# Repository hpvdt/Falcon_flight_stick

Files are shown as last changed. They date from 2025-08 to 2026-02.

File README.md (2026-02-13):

# Falcon Flight Stick
A custom-designed **flight control stick** for the Falcon Aircraft project — designing both **hardware and firmware** for force sensing, CAN communication, and USB HID joystick interfacing.




---

## Overview
The **Falcon Flight Stick** is a force-sensing joystick that measures user input via strain gauges and communicates with the aircraft’s control system through **CAN bus** or to a computer host via **USB-C**.  
This project demonstrates my ability to proficiently design, route, and program an embedded system from the ground up — including power delivery, signal integrity, and firmware architecture.

---

## Key Features
- **MCU Core:** STM32F103CBU6 managing all board-level events with an external 8Mhz Oscillator
- **Sensing System:** Three strain gauges read via a precision Texas Instruments ADS131M03IRUK ADC (32-bit SPI interface)  
- **Connectivity:**  
  - USB-C (HID joystick or virtual COM port)  
  - CAN bus daisy-chain communication  
- **Memory:** 1×128-byte EEPROM for calibration data 
- **Power System:**  
  - TI TPS62177 step-down converter for higher current ditial power
  - ADI LT1962 LDO (3.3V)  for low noise, low current analog power
  - Automatic protection between USB-C and LiPo (12V) sources 
- **PCB Stackup:** 4-layer board with separated analog/digital planes for signal integrity
- **Breakout Button Matrix:**
  - button matrix allowing for a hotswappable and fully customizable button interface on the joystick
  - Up to 25 individual buttons, all allowable for interrupts

---

## Hardware Design

### Hardware Repository
The latest hardware version is **Falcon Flight Stick Rev5**.  
Previous revisions were experimental or undocumented.

### Design Breakdown


The STM32 MCU is programmed through **ST-LinkV3 (SWD)** and communicates via **UART** for debug and development.  
Differential USB data lines enable HID or COM functionality, depending on firmware.  

Strain gauge signals are processed through a TI ADC, which triggers SPI reads via a DRDY interrupt.  
Processed values are sent to the servo controller board (via CAN) or USB interface.  

---

## Power Architecture


The power subsystem ensures stable operation from multiple sources:
- **12V LiPo (CAN chain)** or **5V USB-C**
- Both inputs are protected from backfeed
- Outputs:  
  - 3.3V Digital (MCU, logic)  
  - 3.3V Analog (ADC, strain gauge front-end)

These rails are physically isolated to minimize noise and ground-reference drift.

---

## Schematics
Full schematic set:  
Schematic

---

## PCB Layout

### Summary
- 4-layer stackup for power and noise isolation  
- Separated analog/digital ground and power planes  
- Power trace widths sized by current draw  
- Labelled parts for developer readability  

### Views
**Full Layout:**  


**Layer 1: Signal**  


**Layer 2: Power**  


**Layer 3: GND / AGND**  


**Layer 4: Signal 2**  


---

## 3D Model



---

## Firmware (Planned / In Progress)

Example outline:
- USB HID joystick emulation via STM32 HAL  
- CAN message handling for actuator control  
- ADC data acquisition and digital filtering  
- EEPROM calibration storage  

---

## Tools Used
- **KiCad 8.0** – PCB and schematic design  
- **STM32CubeIDE** – Firmware development  & MCU pinout planning
- **JLCPCB** – Fabrication and assembly  
- **SolidWorks** – 3D mechanical integration  
- **GitHub / Git** – Version control  

---

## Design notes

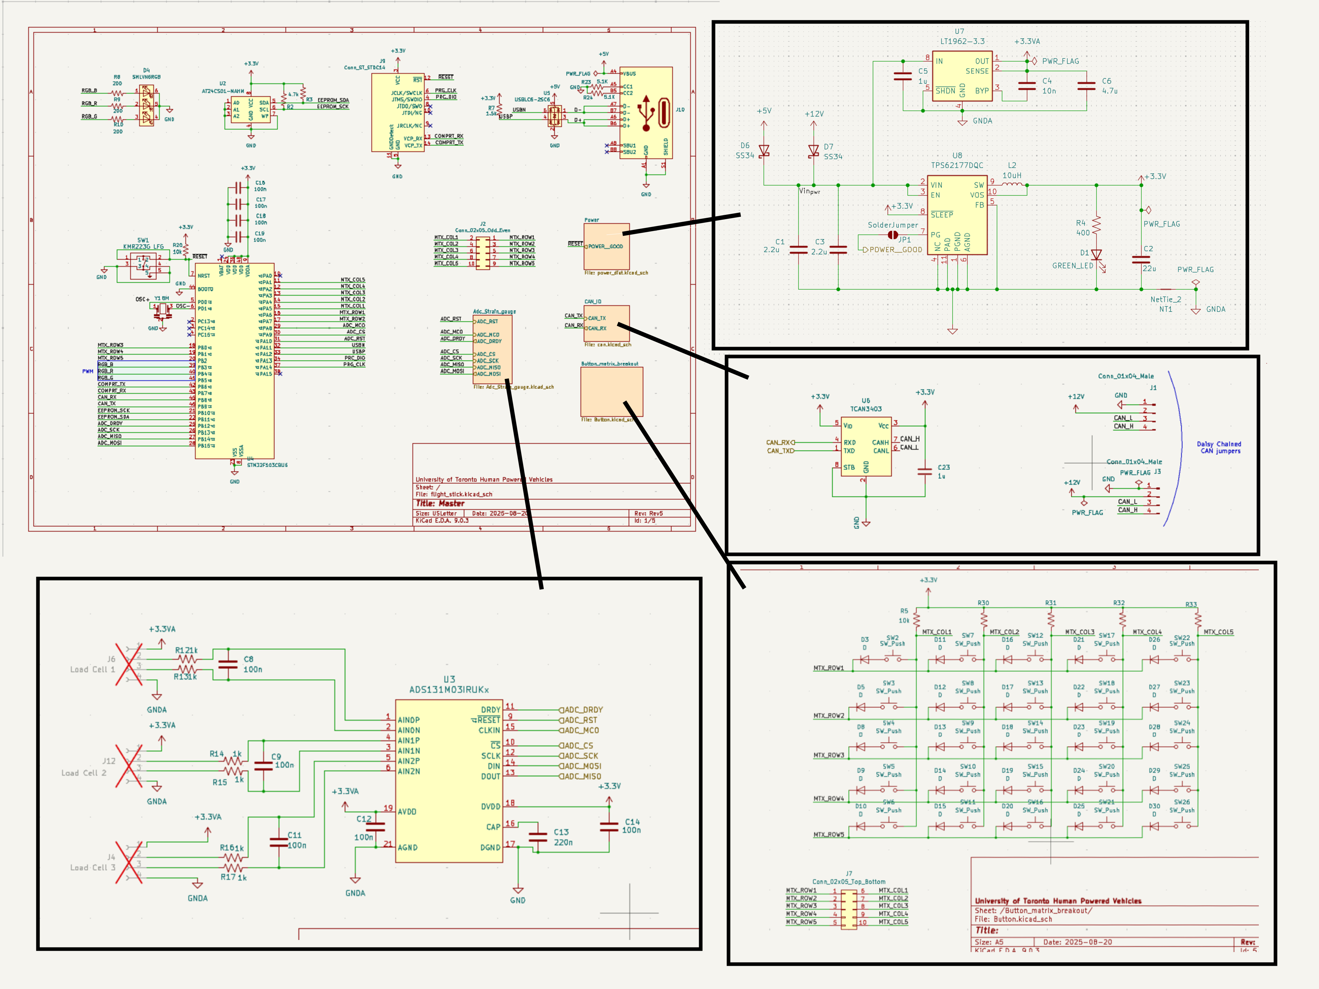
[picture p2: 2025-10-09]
hardware/PCBSchematic.jpg

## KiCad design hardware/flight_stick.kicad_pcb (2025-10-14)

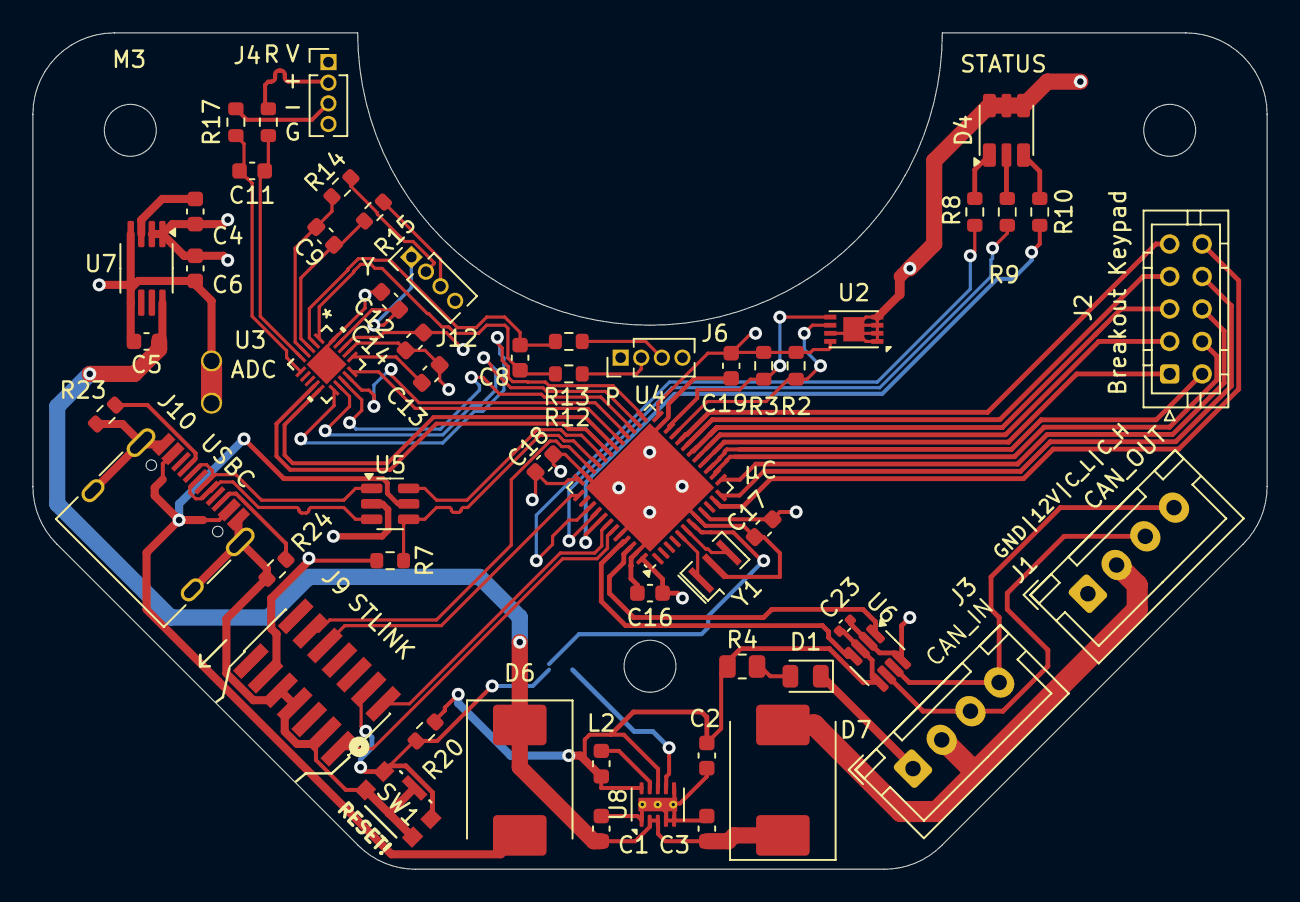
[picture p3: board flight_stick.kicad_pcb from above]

Board: 4 copper layers, 76.0 x 51.5 mm, 60 parts (1 on the bottom side), 66 nets.

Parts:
C1, C3: 2.2u; C_0603_1608Metric
C2: 22u; C_0603_1608Metric
C4: 10n; C_0603_1608Metric
C5: 1u; C_0603_1608Metric
C6: 4.7u; C_0603_1608Metric
C8, C9, C11, C12, C14, C16, C17, C18, C19: 100n; C_0603_1608Metric
C13: 220n; C_0603_1608Metric
C23: 1u; C_0402_1005Metric
D1: GREEN_LED; LED_0805_2012Metric
D4: SMLVN6RGB; LED_ROHM_SMLVN6
D6, D7: SS34; D_SMC
H1, H2, H3: MountingHole; MountingHole_3.2mm_M3
J1, J3: Conn_01x04_Male; JST_XH_B4B-XH-A_1x04_P2.50mm_Vertical
J2: Conn_02x05_Odd_Even; JST_PHD_B10B-PHDSS_2x05_P2.00mm_Vertical
J4: Load Cell 3; PinHeader_1x04_P1.27mm_Vertical
J6: Load Cell 1; PinHeader_1x04_P1.27mm_Vertical
J9: Conn_ST_STDC14; PinHeader_2x07_P1.27mm_Vertical_SMD
J10: USB_C_Receptacle_USB2.0; USB_C_Receptacle_HRO_TYPE-C-31-M-12
J12: Load Cell 2; PinHeader_1x04_P1.27mm_Vertical
JP1: SolderJumper; SolderJumper-2_P1.3mm_Open_TrianglePad1.0x1.5mm
L2: 10uH; L_0603_1608Metric
NT1: NetTie_2; NetTie-2_THT_Pad1.0mm
R2, R3: 4.7k; R_0603_1608Metric
R4: 400; R_0805_2012Metric
R7: 1.5k; R_0603_1608Metric
R8, R9, R10: 200; R_0603_1608Metric
R12, R13, R14, R15, R16, R17: 1k; R_0603_1608Metric
R20: 10k; R_0603_1608Metric
R23, R24: 5.1K; R_0603_1608Metric
SW1: KMR223G LFG; KMR2_G_CNK
U2: AT24CS01-MAHM; DFN-8-1EP_3x2mm_P0.5mm_EP1.3x1.5mm
U3: ADS131M03IRUKx; QFN_WQFN_RUK_TEX
U4: STM32F103CBU6; QFN-48-1EP_7x7mm_P0.5mm_EP5.6x5.6mm
U5: USBLC6-2SC6; SOT-23-6
U6: TCAN3403; TSOT-23-8
U7: LT1962-3.3; MSOP-8_3x3mm_P0.65mm
U8: TPS62177DQC; WSON-10-1EP_2x3mm_P0.5mm_EP0.84x2.4mm_ThermalVias
Y1: 8M; Resonator_SMD_Murata_CSTxExxV-3Pin_3.0x1.1mm

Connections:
+3.3V: C2.1, C14.1, C16.2, C17.2, C18.2, C19.1, C23.1, J9.3 (VCC), L2.2, R2.1, R3.1, R4.1, R7.1, R20.1, U2.8 (VCC), U3.18 (DVDD), U4.9 (VDDA), U4.24 (VDD), U4.36 (VDD), U4.48 (VDD), U6.3 (V_{CC}), U6.5 (V_{IO}), U8.8 (~SLEEP), U8.10 (VOS)
+3.3VA: C4.1, C6.1, C12.1, J4.1, J6.1, J12.1, U3.19 (AVDD), U7.1 (OUT), U7.2 (SENSE)
+5V: D6.2 (A), J10.A4 (VBUS), J10.A9 (VBUS), J10.B4 (VBUS), J10.B9 (VBUS), U5.5 (VBUS)
+12V: D7.2 (A), J1.2, J3.2
/ADC_CS: U3.10 (~CS), U4.30 (PA9)
/ADC_DRDY: U3.11 (DRDY), U4.25 (PB12)
/ADC_MCO: U3.15 (CLKIN), U4.29 (PA8)
/ADC_MISO: U3.13 (DOUT), U4.27 (PB14)
/ADC_MOSI: U3.14 (DIN), U4.28 (PB15)
/ADC_RST: U3.9 (~RESET), U4.31 (PA10)
/ADC_SCK: U3.12 (SCLK), U4.26 (PB13)
/CAN_IO/CAN_H: J1.4, J3.4, U6.7 (CANH)
/CAN_IO/CAN_L: J1.3, J3.3, U6.6 (CANL)
/CAN_RX: U4.45 (PB8), U6.4 (RXD)
/CAN_TX: U4.46 (PB9), U6.1 (TXD)
/COMPRT_RX: J9.13 (VCP_RX), U4.43 (PB7)
/COMPRT_TX: J9.14 (VCP_TX), U4.42 (PB6)
/D+: J10.A6 (D+), J10.B6 (D+), U5.3 (I/O2)
/D-: J10.A7 (D-), J10.B7 (D-), U5.1 (I/O1)
/EEPROM_SCK: R2.2, U2.6 (SCL), U4.21 (PB10)
/EEPROM_SDA: R3.2, U2.5 (SDA), U4.22 (PB11)
/MTX_COL1: J2.2, U4.15 (PA5)
/MTX_COL2: J2.4, U4.14 (PA4)
/MTX_COL3: J2.6, U4.13 (PA3)
/MTX_COL4: J2.8, U4.12 (PA2)
/MTX_COL5: J2.10, U4.11 (PA1)
/MTX_ROW1: J2.1, U4.16 (PA6)
/MTX_ROW2: J2.3, U4.17 (PA7)
/MTX_ROW3: J2.5, U4.18 (PB0)
/MTX_ROW4: J2.7, U4.19 (PB1)
/MTX_ROW5: J2.9, U4.20 (PB2)
/OSC+: U4.5 (PD0), Y1.1
/OSC-: U4.6 (PD1), Y1.3
/PRC_DIO: J9.4 (JTMS/SWDIO), U4.34 (PA13)
/PRG_CLK: J9.6 (JCLK/SWCLK), U4.37 (PA14)
/Power/Vin_{pwr}: C1.1, C3.1, C5.1, D6.1 (K), D7.1 (K), U7.8 (IN), U8.2 (VIN), U8.3 (EN)
/RGB_B: R8.1, U4.39 (PB3)
/RGB_G: R10.1, U4.41 (PB5)
/RGB_R: R9.1, U4.40 (PB4)
/USBN: U4.32 (PA11), U5.6 (I/O1)
/USBP: R7.2, U4.33 (PA12), U5.4 (I/O2)
/~RESET: J9.12 (~RST), JP1.1 (A), R20.2, SW1.1, SW1.2, U4.7 (NRST)
GND: C1.2, C2.2, C3.2, C13.2, C14.2, C16.1, C17.1, C18.1, C19.2, C23.2, D1.1 (K), D4.4 (GK), D4.5 (RK), D4.6 (BK), J1.1, J3.1, J9.5 (GND), J9.7 (GND), J9.11 (GNDDetect), J10.A1 (GND), J10.A12 (GND), J10.B1 (GND), J10.B12 (GND), J10.S1 (SHIELD), NT1.2, R23.1, R24.1, SW1.3, SW1.4, SW1.5, U2.1 (A0), U2.2 (A1), U2.3 (A2), U2.4 (GND), U2.7 (WP), U2.9 (GND), U3.17 (DGND), U4.8 (VSSA), U4.23 (VSS), U4.35 (VSS), U4.44 (BOOT0), U4.47 (VSS), U4.49 (VSS), U5.2 (GND), U6.2 (GND), U6.8 (STB), U8.1 (PGND), U8.4 (NC), U8.5 (FB), U8.6 (AGND), U8.11 (PAD), Y1.2
GNDA: C5.2, C6.2, C12.2, J4.4, J6.4, J12.4, NT1.1, U3.20 (AGND), U3.21 (AGND), U7.4 (GND), U7.5 (~SHDN)
unnamed: D1.2 (A), R4.2
unnamed: D4.1 (BA), R8.2
unnamed: D4.3 (GA), R10.2
unnamed: D4.2 (RA), R9.2
unnamed: J4.2, R16.1
unnamed: J4.3, R17.1
unnamed: J6.2, R12.1
unnamed: J6.3, R13.1
unnamed: J10.A5 (CC1), R23.2
unnamed: J10.B5 (CC2), R24.2
unnamed: J12.2, R14.1
unnamed: J12.3, R15.1
unnamed: JP1.2 (B), U8.7 (PG)
unnamed: C8.1, R13.2, U3.2 (AIN0N)
unnamed: C8.2, R12.2, U3.1 (AIN0P)
unnamed: C9.1, R15.2, U3.3 (AIN1N)
unnamed: C9.2, R14.2, U3.4 (AIN1P)
unnamed: C11.1, R17.2, U3.6 (AIN2N)
unnamed: C11.2, R16.2, U3.5 (AIN2P)
unnamed: C13.1, U3.16 (CAP)
unnamed: C4.2, U7.3 (BYP)
unnamed: L2.1, U8.9 (SW)

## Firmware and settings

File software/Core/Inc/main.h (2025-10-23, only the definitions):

#define MTX_COL5_Pin GPIO_PIN_1
#define MTX_COL5_GPIO_Port GPIOA
#define MTX_COL4_Pin GPIO_PIN_2
#define MTX_COL4_GPIO_Port GPIOA
#define MTX_COL3_Pin GPIO_PIN_3
#define MTX_COL3_GPIO_Port GPIOA
#define MTX_COL2_Pin GPIO_PIN_4
#define MTX_COL2_GPIO_Port GPIOA
#define MTX_COL1_Pin GPIO_PIN_5
#define MTX_COL1_GPIO_Port GPIOA
#define MTX_ROW1_Pin GPIO_PIN_6
#define MTX_ROW1_GPIO_Port GPIOA
#define MTX_ROW2_Pin GPIO_PIN_7
#define MTX_ROW2_GPIO_Port GPIOA
#define MTX_ROW3_Pin GPIO_PIN_0
#define MTX_ROW3_GPIO_Port GPIOB
#define MTX_ROW4_Pin GPIO_PIN_1
#define MTX_ROW4_GPIO_Port GPIOB
#define MTX_ROW5_Pin GPIO_PIN_2
#define MTX_ROW5_GPIO_Port GPIOB
#define EEP_I2C2_SCL_Pin GPIO_PIN_10
#define EEP_I2C2_SCL_GPIO_Port GPIOB
#define EEP_I2C2_SDA_Pin GPIO_PIN_11
#define EEP_I2C2_SDA_GPIO_Port GPIOB
#define ADC_DRDY_EXTI12_Pin GPIO_PIN_12
#define ADC_DRDY_EXTI12_GPIO_Port GPIOB
#define ADC_CS_Pin GPIO_PIN_9
#define ADC_CS_GPIO_Port GPIOA
#define ADC_RST_Pin GPIO_PIN_10
#define ADC_RST_GPIO_Port GPIOA
#define RGB_PIN_Pin GPIO_PIN_5
#define RGB_PIN_GPIO_Port GPIOB

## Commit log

2025-08-16 Added REV5 flightstick
    [flight_stick.kicad_pcb, flight_stick.kicad_sch]
2025-08-16 added new voltage reg
    [flight_stick.kicad_sch]
2025-08-18 Added subpages and CAN tranciever
    [Adc_Strain_gauge.kicad_sch, Button.kicad_sch, can.kicad_sch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]
2025-08-18 Fixed ERC errors & CAN module
    [Adc_Strain_gauge.kicad_sch, Button.kicad_sch, can.kicad_sch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]
2025-08-21 Added EEPROM, resolved comments
    [Adc_Strain_gauge.kicad_sch, Button.kicad_sch, can.kicad_sch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]
2025-08-21 Stylistic changes
    [Adc_Strain_gauge.kicad_sch, Button.kicad_sch, flight_stick.kicad_sch]
2025-08-22 revamped button matrix
    [Button.kicad_sch, can.kicad_sch, flight_stick.kicad_sch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]
2025-08-22 Finished footprint assignment and deleted pcb
    [Button.kicad_sch, flight_stick.kicad_pcb, flight_stick.kicad_sch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]
2025-08-22 Began layout placement
    [flight_stick.kicad_pcb]
2025-10-03 modified mcu pin alloc and pre-routing placement
    [Adc_Strain_gauge.kicad_sch, Button.kicad_sch, flight_stick.kicad_pcb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]
2025-10-03 Completed first layout draft
    [Adc_Strain_gauge.kicad_sch, Button.kicad_sch, flight_stick.kicad_pcb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]
2025-10-03 small changes
    [flight_stick.kicad_pcb]
2025-10-05 resolved comments
    [Adc_Strain_gauge.kicad_sch, flight_stick.kicad_pcb, flight_stick.kicad_sch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]
2025-10-06 Updated footprints
    [flight_stick.kicad_pcb]
2025-10-08 updated comments
    [flight_stick.kicad_pcb, flight_stick.kicad_sch]
2025-10-08 tied PG to mcu reset
    [flight_stick.kicad_pcb, flight_stick.kicad_sch, power_dist.kicad_sch]
2025-10-08 clean up traces
    [flight_stick.kicad_pcb]
2025-10-08 Refactor netlist and lock footprints in PCB design
    Renamed the /RESET net to /~{RESET} and updated all references accordingly. Reordered and renumbered net definitions to maintain consistency. Added the 'locked' attribute to multiple footprints for improved layout stability. Updated silkscreen reference positions for R8 and R10. No functional changes to the schematic or board layout.
    [flight_stick.kicad_pcb, flight_stick.kicad_sch, power_dist.kicad_sch]
2025-10-08 changed to in-stock buck regulator
    [flight_stick-CuBottom.gbr, flight_stick-CuIn1.gbr, flight_stick-CuIn2.gbr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]
2025-10-08 Update PCB and Gerber files for new U8 footprint
    Removed an obsolete drawing from the PCB and regenerated all Gerber and production files to reflect the addition of a new U8 footprint. Also deleted an outdated Gerber ZIP archive.
    [flight_stick-CuBottom.gbr, flight_stick-CuIn1.gbr, flight_stick-CuIn2.gbr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]
2025-10-09 Add PCB sheet schematic
2025-10-14 changed 0402 cap part # and regenerated prod files
    [can.kicad_sch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]
2025-10-23 Initialize software dev
    [flight_stick.kicad_sch]
2025-10-23 Changed PWM pin to GPIO for successful LED blink sanity test
2026-02-13 Add visible ground layer for Layer 1 and Layer 4 in README
    Added additional images for Layer 1 and Layer 4 in the README.

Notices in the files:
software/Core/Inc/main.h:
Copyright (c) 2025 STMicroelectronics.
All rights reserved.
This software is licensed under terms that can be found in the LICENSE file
